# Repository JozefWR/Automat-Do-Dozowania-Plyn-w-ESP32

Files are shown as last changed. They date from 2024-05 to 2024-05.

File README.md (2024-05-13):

# Automat do Dozowania Płynów z Obsługą Zdalną (ESP32_BT)

## Opis projektu

Automat do dozowania płynów z możliwością obsługi zdalnej to zaawansowany projekt inżynierski, który łączy w sobie elektronikę i programowanie do stworzenia zintegrowanego systemu sterowania. Projekt został wykonany na Politechnice Koszalińskiej jako praca dyplomowa.

## Instalacja i konfiguracja

1. Sklonuj to repozytorium na swoje lokalne środowisko.
2. Zapoznaj się z dokumentacją techniczną zawartą w pliku `praca_inzynierska.pdf` dla szczegółów dotyczących budowy i działania urządzenia.
3. Zainstaluj wymagane oprogramowanie i biblioteki, jak opisano w dokumentacji.

## Schematy montażu i testowania

Nazwy elementów, moduły, zdjęcia i schematy montażu oraz testowania znajdują się w pliku `praca_inzynierska.pdf`. Wizualizacje te pomogą w zrozumieniu dokładnego procesu składania urządzenia i jego konfiguracji.

## Programowanie

Programowanie mikrokontrolera ESP32 odbywa się przez Arduino IDE. Kod źródłowy oraz szczegółowe instrukcje znajdują się w folderze i pliku `program_ESP32`.

## Zdjęcia i rysunki

- GotowyPrototyp - zdjęcie gotowego prototypu urządzenia.
- SchematKomunikacji - schemat komunikacji.
- SchematPłytkiPCB - schemat elektroniczny płytki PCB.
- PłytkaPCB
 - płytka PCB.
- SchematBlokowy - schemat blokowy działania automatu.
- Menu
  Tarowanie
  Nalewanie
- zrzuty ekranu z aplikacji mobilnej.

## Wykorzystane technologie

Projekt wykorzystuje następujące technologie:
- **Mikrokontroler ESP32**: Serce systemu, odpowiada za sterowanie działaniem urządzenia i komunikację zdalną.
- **Arduino IDE**: Środowisko programistyczne używane do pisania kodu dla mikrokontrolera.
- **Eagle CAD**: Oprogramowanie do projektowania płytek PCB, używane do tworzenia schematów elektronicznych i layoutów PCB.
- **Technologie mobilne**: Aplikacja mobilna umożliwia zdalne sterowanie urządzeniem i monitorowanie jego stanu.
- **Bluetooth**: Komunikacja bezprzewodowa między mikrokontrolerem a aplikacją mobilną.

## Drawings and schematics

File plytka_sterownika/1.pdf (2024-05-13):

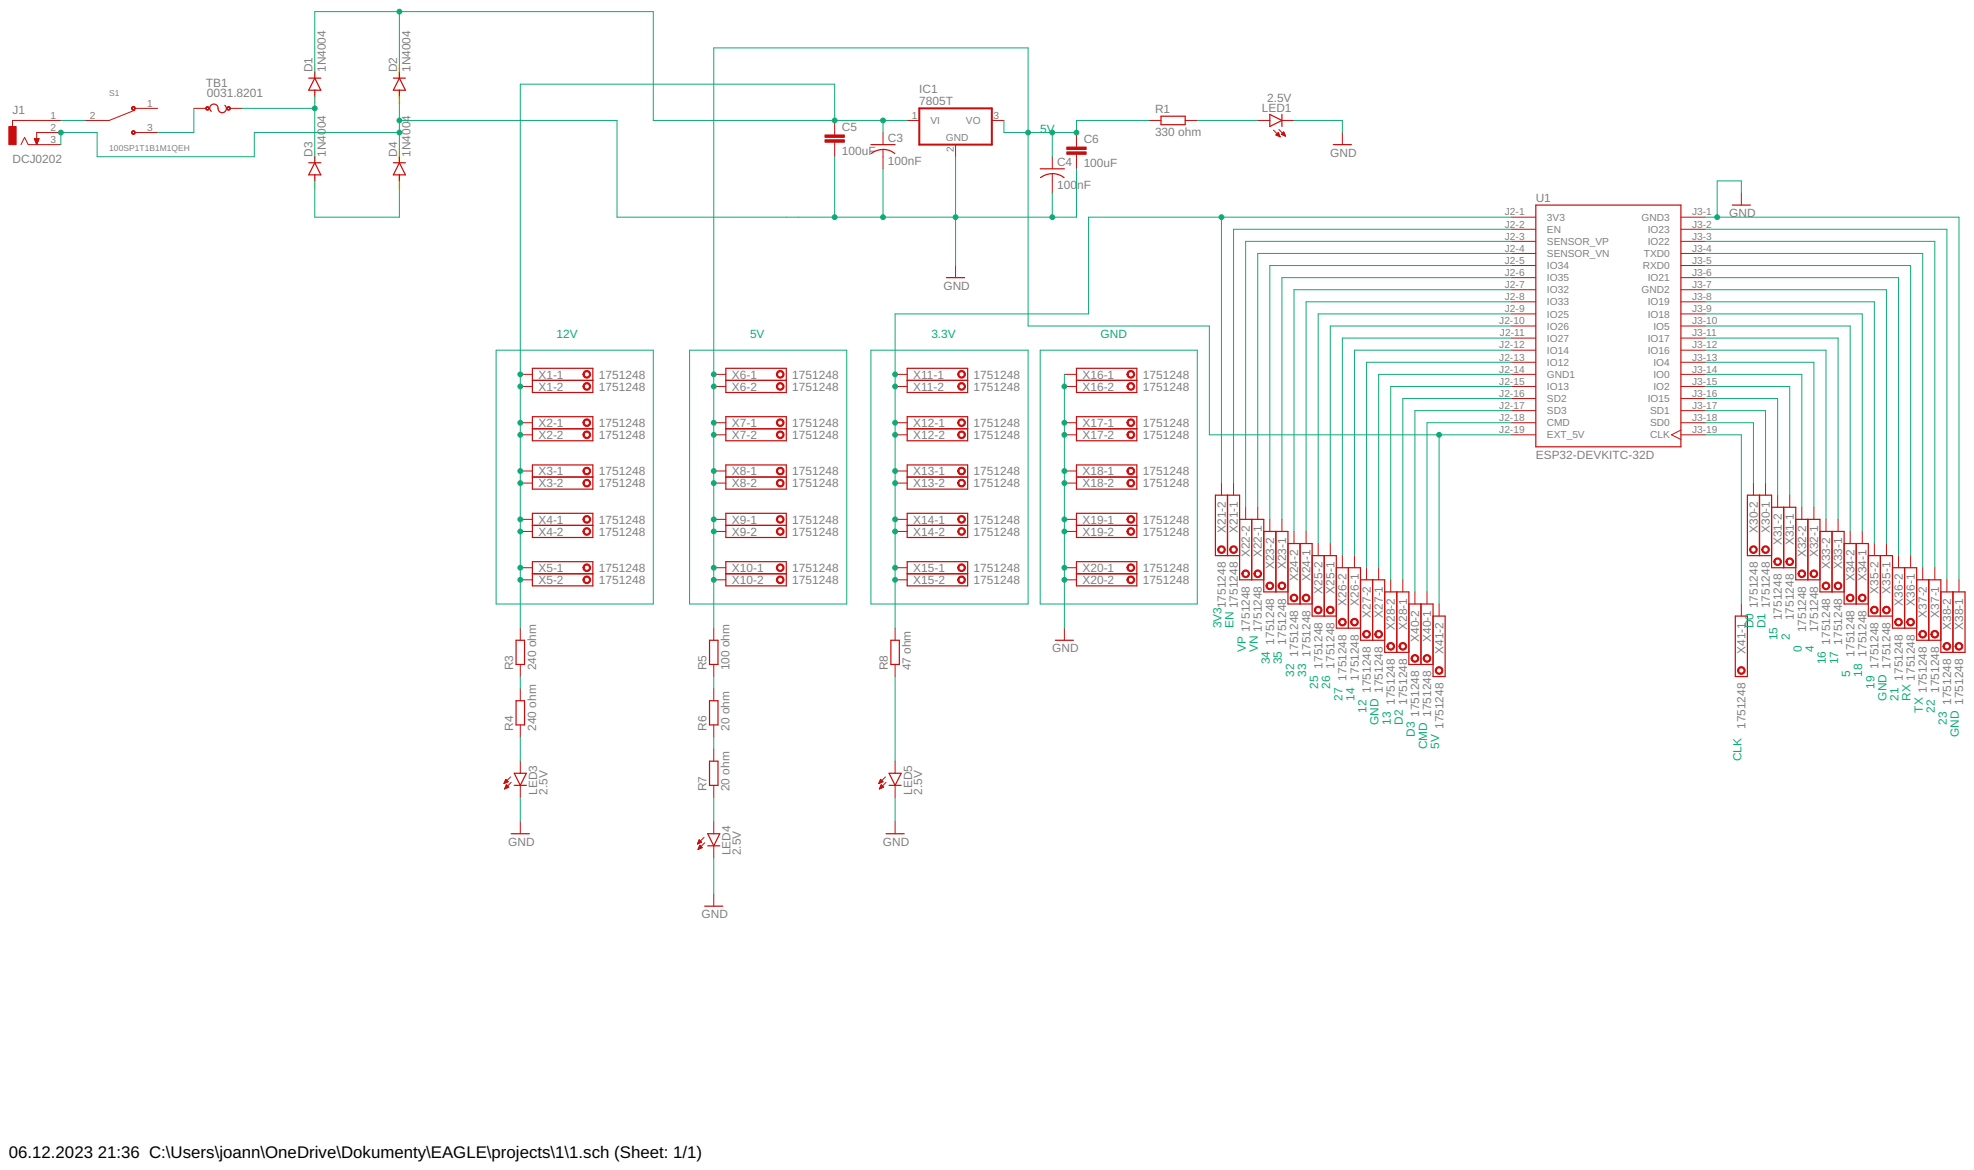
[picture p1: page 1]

J2-5 | J3-5 TXD0
J2-6 | J3-6 RXD0

J2-7 | J3-7
J2-8 | J3-8 GND2

J2-9 | J3-9
J2-10 | J3-10
J2-11 | J3-11
J2-12 | J3-12

06.12.2023 21:36 C:\Users\joann\OneDrive\Dokumenty\EAGLE\projects\1\1.sch (Sheet: 1/1)

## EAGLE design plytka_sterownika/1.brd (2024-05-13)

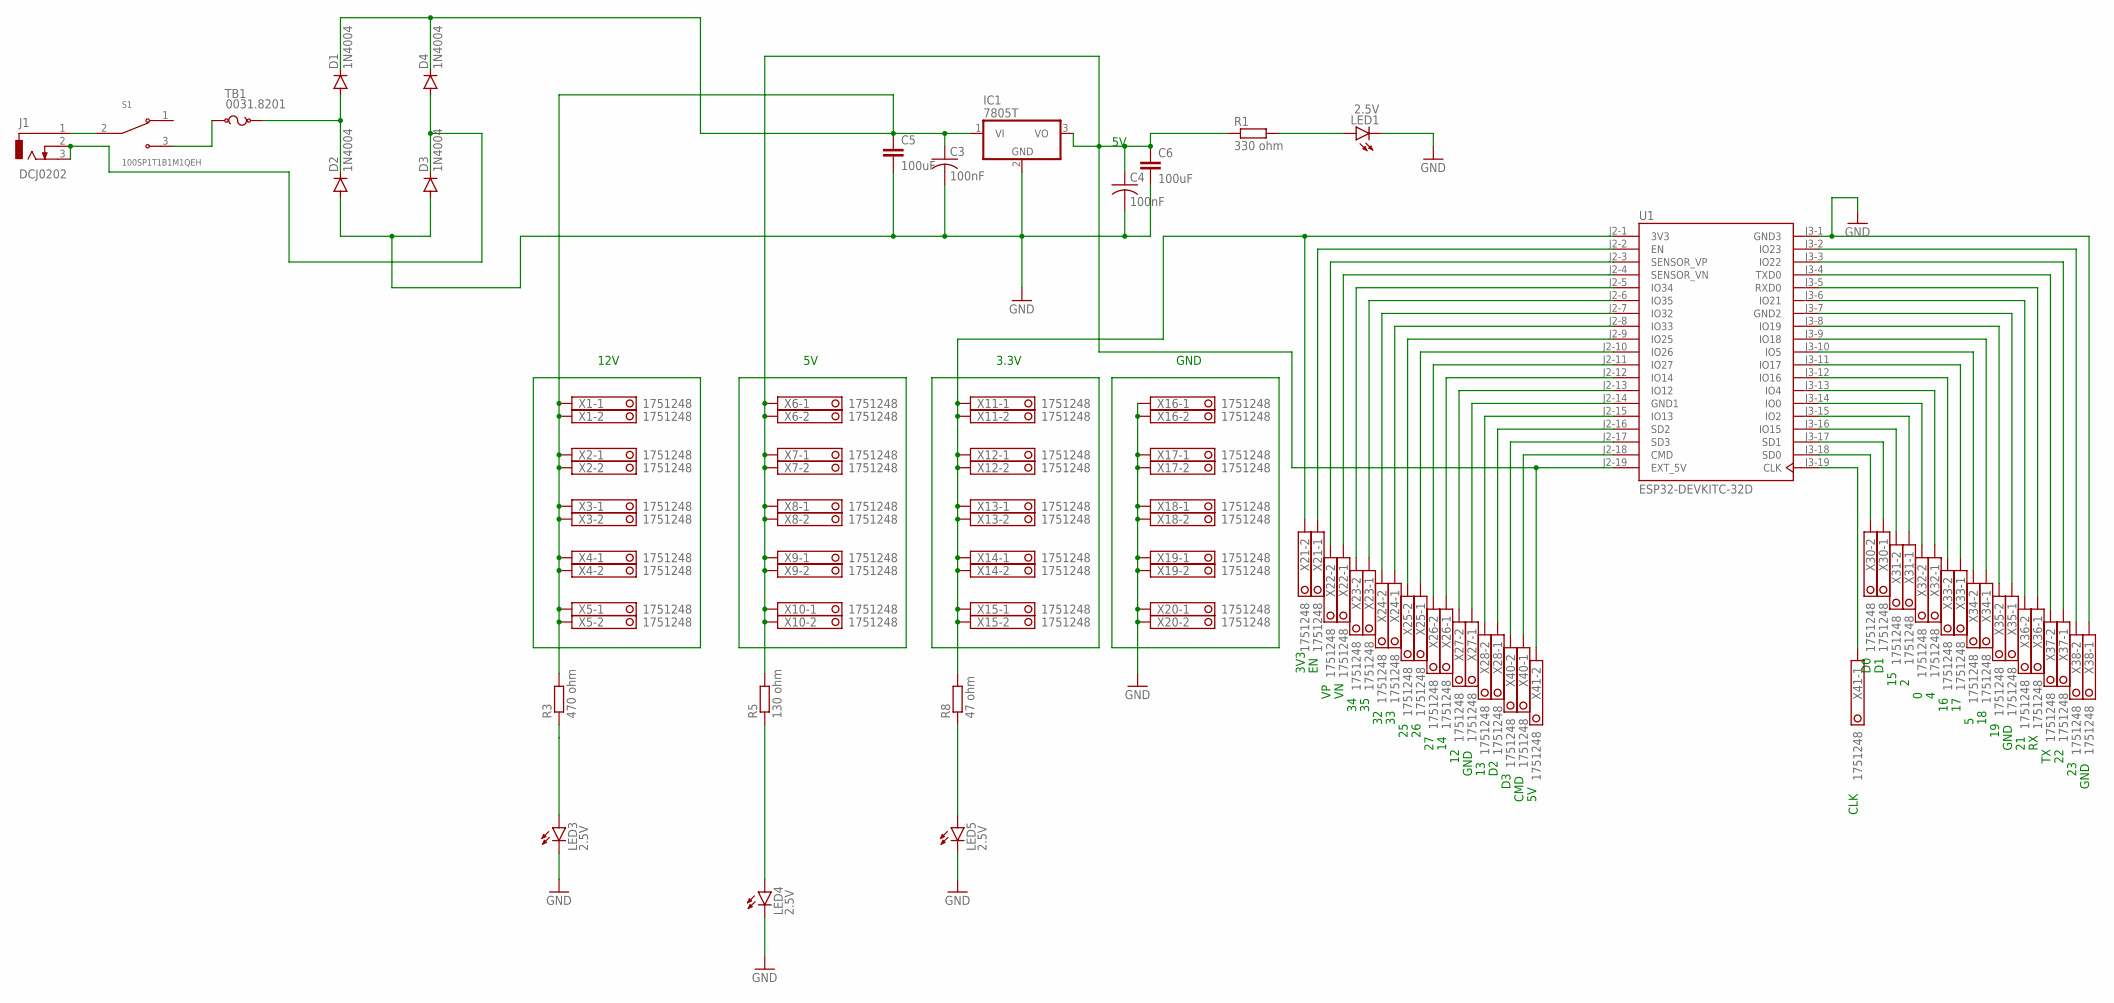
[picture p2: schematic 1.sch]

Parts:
C3, C4: 100nF; C025-024X044
C5, C6: 100uF; C025-050X050
D1, D2, D3, D4: 1N4004; DO41-10
IC1: 7805T; TO220H
J1: DCJ0202
LED1, LED3, LED4, LED5: 2.5V; LED3MM
R1: 330 ohm; 0207/10
R3: 470 ohm; 0207/10
R5: 130 ohm; 0207/10
R8: 47 ohm; 0207/10
S1: 100SP1T1B1M1QEH; SW_100SP1T1B1M1QEH
TB1: 0031.8201; SCHURTER_0031.8201
U1: ESP32-DEVKITC-32D; MODULE_ESP32-DEVKITC-32D
X1, X2, X3, X4, X5, X6, X7, X8, X9, X10, X11, X12, X13, X14, X15, X16, X17, X18, X19, X20, X21, X22, X23, X24, X25, X26, X27, X28, X30, X31, X32, X33, X34, X35, X36, X37, X38, X40, X41: 1751248

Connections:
GND: C3.2, C4.2, C5.2, C6.2, D2.A, D3.A, IC1.2 (GND), LED1.K (C), LED3.K (C), LED4.K (C), LED5.K (C), U1.J3-1 (GND3), X16.1, X16.2, X17.1, X17.2, X18.1, X18.2, X19.1, X19.2, X20.1, X20.2, X38.1
unnamed: D3.C, D4.A, J1.2, J1.3
unnamed: C4.1, C6.1, IC1.3 (VO), R1.1, R5.2, U1.J2-19 (EXT_5V), X6.1, X6.2, X7.1, X7.2, X8.1, X8.2, X9.1, X9.2, X10.1, X10.2, X41.2
unnamed: LED1.A, R1.2
unnamed: R8.2, U1.J2-1 (3V3), X11.1, X11.2, X12.1, X12.2, X13.1, X13.2, X14.1, X14.2, X15.1, X15.2, X21.2
unnamed: U1.J2-2 (EN), X21.1
unnamed: U1.J2-3 (SENSOR_VP), X22.2
unnamed: U1.J2-4 (SENSOR_VN), X22.1
unnamed: U1.J2-5 (IO34), X23.2
unnamed: U1.J2-6 (IO35), X23.1
unnamed: U1.J2-7 (IO32), X24.2
unnamed: U1.J2-8 (IO33), X24.1
unnamed: U1.J2-9 (IO25), X25.2
unnamed: U1.J2-10 (IO26), X25.1
unnamed: U1.J2-11 (IO27), X26.2
unnamed: U1.J2-12 (IO14), X26.1
unnamed: U1.J2-13 (IO12), X27.2
unnamed: U1.J2-14 (GND1), X27.1
unnamed: U1.J2-15 (IO13), X28.2
unnamed: U1.J2-16 (SD2), X28.1
unnamed: U1.J2-17 (SD3), X40.2
unnamed: U1.J2-18 (CMD), X40.1
unnamed: U1.J3-19 (CLK), X41.1
unnamed: U1.J3-18 (SD0), X30.2
unnamed: U1.J3-17 (SD1), X30.1
unnamed: U1.J3-16 (IO15), X31.2
unnamed: U1.J3-15 (IO2), X31.1
unnamed: U1.J3-14 (IO0), X32.2
unnamed: U1.J3-13 (IO4), X32.1
unnamed: U1.J3-12 (IO16), X33.2
unnamed: U1.J3-11 (IO17), X33.1
unnamed: U1.J3-10 (IO5), X34.2
unnamed: U1.J3-9 (IO18), X34.1
unnamed: U1.J3-8 (IO19), X35.2
unnamed: U1.J3-7 (GND2), X35.1
unnamed: U1.J3-6 (IO21), X36.2
unnamed: U1.J3-5 (RXD0), X36.1
unnamed: U1.J3-4 (TXD0), X37.2
unnamed: U1.J3-3 (IO22), X37.1
unnamed: U1.J3-2 (IO23), X38.2
unnamed: LED3.A, R3.1
unnamed: D1.A, D2.C, TB1.2
unnamed: S1.3, TB1.1
unnamed: C3.1, C5.1, D1.C, D4.C, IC1.1 (VI), R3.2, X1.1, X1.2, X2.1, X2.2, X3.1, X3.2, X4.1, X4.2, X5.1, X5.2
unnamed: J1.1, S1.2
unnamed: LED4.A, R5.1
unnamed: LED5.A, R8.1

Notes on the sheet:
12V
3.3V
GND
CMD
3V3
CLK

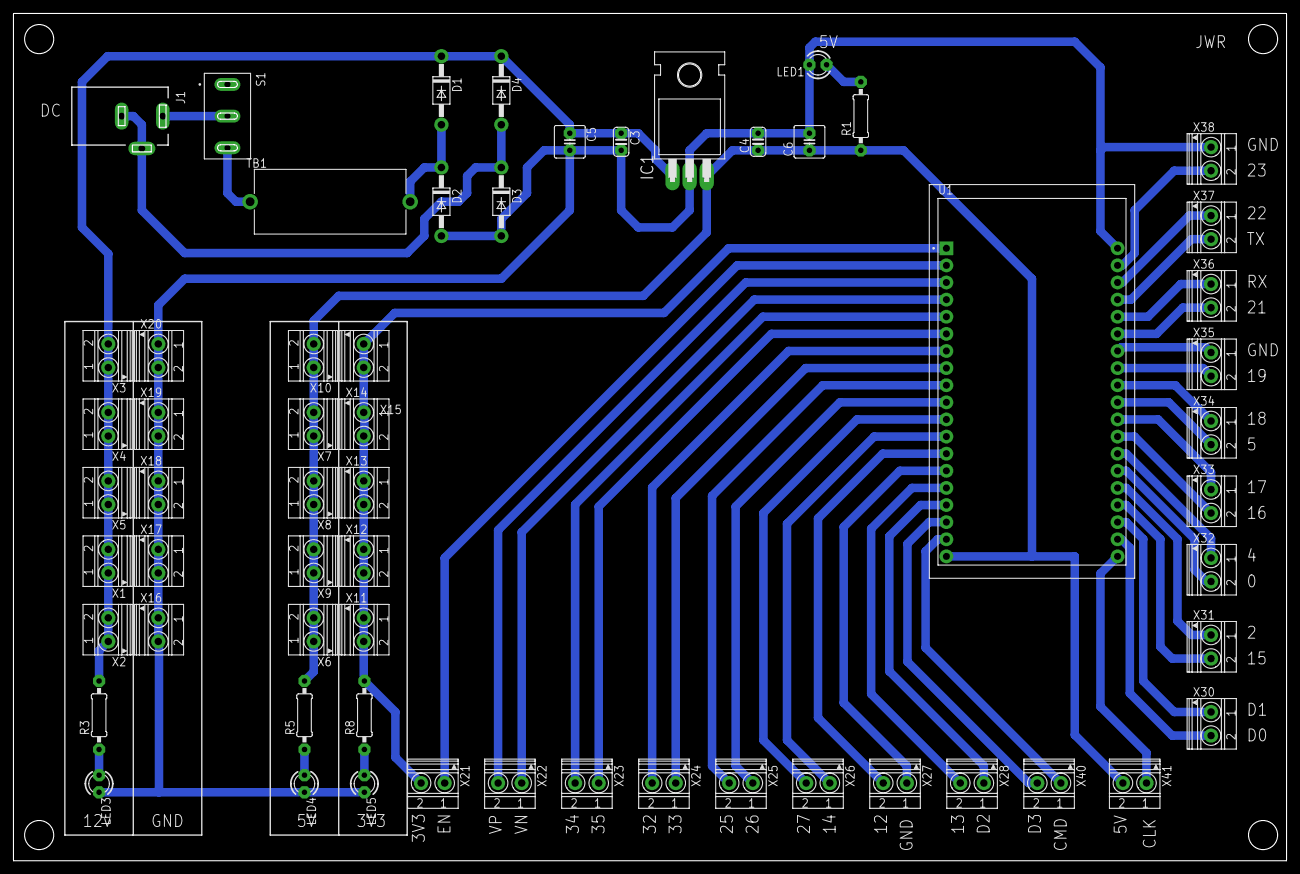
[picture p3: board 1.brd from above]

Board: 2 copper layers, 188.9 x 125.7 mm, 60 parts (0 on the bottom side), 47 nets.

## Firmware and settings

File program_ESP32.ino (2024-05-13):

#include <DFRobot_HX711_I2C.h>
#include <BluetoothSerial.h>
#include <Wire.h> 
#include <LiquidCrystal_I2C.h>

LiquidCrystal_I2C lcd(0x27, 16, 2);  // Adres I2C i rozmiar wyświetlacza
DFRobot_HX711_I2C MojaWaga;
BluetoothSerial SerialBT;

void setup() {
  Serial.begin(9600);
  SerialBT.begin("AutomatDoNapoji"); // Nazwa urządzenia Bluetooth
  lcd.init();                          // Inicjalizacja wyświetlacza
  lcd.backlight();                     // Włączenie podświetlenia
  delay(20000);
  inicjalizujAutomat();
}

void loop() {
  wyslijNaLCD("Wybierz napoj");
  wyslijNaLCD2("Z menu w apce!");
  wyslij("Wybierz napoj z menu:");
  bool restartLoop = false;

  wyswietlMenu();
  int wyborMenu = pobierzWyborMenu();
  if (wyborMenu > 0 && wyborMenu <= 20) {
    if (tarujWage()) {
      if (!przygotujNapojNaPodstawieWyboru(wyborMenu)) {
        restartLoop = true;
      }
    }
  } else {
    wyslij("Nieprawidlowy wybor");
  }

  if (restartLoop) {
    return;
  }

  wyczyscBuforySzeregowe();
}

void inicjalizujAutomat() {
  MojaWaga.begin();
  MojaWaga.setCalibration(2236.f);

  pinMode(15, OUTPUT); // Sok pomarańczowy
  digitalWrite(15, HIGH);
  pinMode(16, OUTPUT); // Sok jabłkowy
  digitalWrite(16, HIGH);
  pinMode(17, OUTPUT); // Sok ananasowy
  digitalWrite(17, HIGH);
  pinMode(18, OUTPUT); // Woda gazowana
  digitalWrite(18, HIGH);
  pinMode(19, OUTPUT); // Mleko
  digitalWrite(19, HIGH);

  pinMode(32, OUTPUT); // Syrop malinowy
  digitalWrite(32, HIGH);
  pinMode(33, OUTPUT); // Cytryna wyciskana
  digitalWrite(33, HIGH);
  pinMode(25, OUTPUT); // Tonik
  digitalWrite(25, HIGH);
  pinMode(26, OUTPUT); // Cola
  digitalWrite(26, HIGH);
  pinMode(27, OUTPUT); // Lemoniada gazowana
  digitalWrite(27, HIGH);
}

void wyslij(String wiadomosc) {
  Serial.println(wiadomosc);
  SerialBT.println(wiadomosc);
}

void wyslijNaLCD(String wiadomosc) {
  lcd.clear();
  lcd.setCursor(0, 0);
  lcd.print(wiadomosc);
}

void wyslijNaLCD2(String wiadomosc) {
  lcd.setCursor(0, 1);
  lcd.print("                "); // Czyszczenie drugiej linii
  lcd.setCursor(0, 1);
  lcd.print(wiadomosc);
}

void wyswietlMenu() {
  wyslij("1. Orzeźwiający Mix");
  wyslij("2. Jesienna Harmonia");
  wyslij("3. Tropikalna Bryza");
  wyslij("4. Malinowa Rozkosz");
  wyslij("5. Cytrusowy Zing");
  wyslij("6. Klasyczna Cola Mix");
  wyslij("7. Lemoniadowe Orzeźwienie");
  wyslij("8. Klasyczna Cola Mix");
  wyslij("9. Pomarańczowa Fantazja");
  wyslij("10. Ananasowa Fuzja");
  wyslij("11. Lemon & Cola");
  wyslij("12. Słoneczny Koktajl");
  wyslij("12. Mleczny Twist");
  wyslij("13. Lekka Cola");
  wyslij("14. Cytrynowy Chłód");
  wyslij("15. Malinowy Dream");
  wyslij("16. Egzotyczny Mix");
  wyslij("17. Orzeźwiający Cytrus");
  wyslij("18. Lemoniada Plus");
  wyslij("19. Tropikalna Cola");
  wyslij("20. Malinowa Cola");
}

int pobierzWyborMenu() {
  while (!(SerialBT.available() || Serial.available())) {
    delay(10);
  }
  
  if (SerialBT.available()) {
    return SerialBT.parseInt();
  } else if (Serial.available()) {
    return Serial.parseInt();
  }
  
  return -1;
}

bool tarujWage() {
  wyslijNaLCD("Tarowanie...");
  wyslijNaLCD2("Ostroznie!");
  wyslij("Umieść szklankę na wadze i naciśnij 't', aby wytarować...");
  wyslij("Naciśnij 'm', aby anulować i wrócić do menu.");
  char result = czekajNaDaneZTimeoutem(15000, 't', 'm');
  if (result == 't') {
    MojaWaga.peel();
    wyslij("Waga wytarowana.");
    return true;
  } else if (result == 'm') {
    wyslij("Wybór anulowany, powrót do menu.");
    return false;
  } else {
    wyslij("Czas na tarowanie upłynął, powrót do menu.");
    return false;
  }
}

char czekajNaDaneZTimeoutem(unsigned long czasTimeoutu, char oczekiwanyZnak, char znakAnulujacy) {
  unsigned long czasStartu = millis();
  while (millis() - czasStartu < czasTimeoutu) {
    if (Serial.available() || SerialBT.available()) {
      char znak = Serial.available() ? Serial.read() : SerialBT.read();
      if (znak == oczekiwanyZnak || znak == znakAnulujacy) {
        wyczyscBuforySzeregowe();
        return znak;
      }
    }
    delay(10);
  }
  return 'x'; // Gdy czas się skończy, zwracamy 'x' jako sygnał upływu czasu
}

bool przygotujNapojNaPodstawieWyboru(int wybor) {
  switch (wybor) {
    case 1: // Orzeźwiający Mix
      if (!nalejSkladnik("Sok pomaranczowy", 30, 15) || !nalejSkladnik("Woda gazowana", 20, 18) || !nalejSkladnik("Lemoniada gazowana", 10, 27) || !nalejSkladnik("Sok jablkowy", 40, 16)) {
        return false;
      }
      break;
    case 2: // Jesienna Harmonia
      if (!nalejSkladnik("Sok jablkowy", 40, 16) || !nalejSkladnik("Lemoniada gazowana", 30, 27) || !nalejSkladnik("Woda gazowana", 30, 18)) {
        return false;
      }
      break;
    case 3: // Tropikalna Bryza
      if (!nalejSkladnik("Sok ananasowy", 25, 17) || !nalejSkladnik("Sok pomaranczowy", 25, 15) || !nalejSkladnik("Tonik", 50, 25)) {
        return false;
      }
      break;
    case 4: // Malinowa Rozkosz
      if (!nalejSkladnik("Mleko", 50, 19) || !nalejSkladnik("Syrop malinowy", 20, 32) || !nalejSkladnik("Woda gazowana", 30, 18)) {
        return false;
      }
      break;
    case 5: // Cytrusowy Zing
      if (!nalejSkladnik("Sok pomaranczowy", 30, 15) || !nalejSkladnik("Sok cytrynowy", 20, 33) || !nalejSkladnik("Cola", 50, 26)) {
        return false;
      }
      break;
    case 6: // Klasyczna Cola Mix
      if (!nalejSkladnik("Cola", 60, 26) || !nalejSkladnik("Woda gazowana", 40, 18)) {
        return false;
      }
      break;
    case 7: // Lemoniadowe Orzeźwienie
      if (!nalejSkladnik("Lemoniada gazowana", 70, 27) || !nalejSkladnik("Sok jablkowy", 30, 16)) {
        return false;
      }
      break;
    case 8: // Pomarańczowa Fantazja
      if (!nalejSkladnik("Sok pomaranczowy", 50, 15) || !nalejSkladnik("Mleko", 25, 19) || !nalejSkladnik("Lemoniada gazowana", 25, 27)) {
        return false;
      }
      break;
    case 9: // Ananasowa Fuzja
      if (!nalejSkladnik("Sok ananasowy", 30, 17) || !nalejSkladnik("Tonik", 40, 25) || !nalejSkladnik("Lemoniada gazowana", 30, 27)) {
        return false;
      }
      break;
    case 10: // Lemon & Cola
      if (!nalejSkladnik("Cola", 50, 26) || !nalejSkladnik("Sok cytrynowy", 50, 33)) {
        return false;
      }
      break;
    case 11: // Słoneczny Koktajl
      if (!nalejSkladnik("Sok pomaranczowy", 50, 15) || !nalejSkladnik("Sok jablkowy", 25, 16) || !nalejSkladnik("Lemoniada gazowana", 25, 27)) {
        return false;
      }
      break;
    case 12: // Mleczny Twist
      if (!nalejSkladnik("Mleko", 70, 19) || !nalejSkladnik("Cola", 30, 26)) {
        return false;
      }
      break;
    case 13: // Lekka Cola
      if (!nalejSkladnik("Cola", 50, 26) || !nalejSkladnik("Woda gazowana", 50, 18)) {
        return false;
      }
      break;
    case 14: // Cytrynowy Chłód
      if (!nalejSkladnik("Tonik", 50, 25) || !nalejSkladnik("Sok cytrynowy", 25, 33) || !nalejSkladnik("Cola", 25, 26)) {
        return false;
      }
      break;
    case 15: // Malinowy Dream
      if (!nalejSkladnik("Syrop malinowy", 50, 32) || !nalejSkladnik("Mleko", 50, 19)) {
        return false;
      }
      break;
    case 16: // Egzotyczny Mix
      if (!nalejSkladnik("Sok ananasowy", 40, 17) || !nalejSkladnik("Sok pomaranczowy", 30, 15) || !nalejSkladnik("Lemoniada gazowana", 30, 27)) {
        return false;
      }
      break;
    case 17: // Orzeźwiający Cytrus
      if (!nalejSkladnik("Sok pomaranczowy", 40, 15) || !nalejSkladnik("Sok cytrynowy", 30, 33) || !nalejSkladnik("Cola", 30, 26)) {
        return false;
      }
      break;
    case 18: // Lemoniada Plus
      if (!nalejSkladnik("Lemoniada gazowana", 70, 27) || !nalejSkladnik("Sok jablkowy", 30, 16)) {
        return false;
      }
      break;
    case 19: // Tropikalna Cola
      if (!nalejSkladnik("Sok ananasowy", 35, 17) || !nalejSkladnik("Cola", 35, 26) || !nalejSkladnik("Tonik", 30, 25)) {
        return false;
      }
      break;
    case 20: // Malinowa Cola
      if (!nalejSkladnik("Syrop malinowy", 40, 32) || !nalejSkladnik("Cola", 60, 26)) {
        return false;
      }
      break;
    default:
      wyslij("Nieprawidłowy wybór. Spróbuj ponownie.");
      return false;
  }
  wyslij("Twój napój jest gotowy! Odbierz go!");
  wyslijNaLCD("Napoj gotowy!");
  wyslijNaLCD2("Odbierz go!");
  return true;
}

bool nalejSkladnik(String skladnik, int waga, int pin) {
  int startowaWaga = MojaWaga.readWeight();
  int aktualnaWaga;
  digitalWrite(pin, LOW); // Rozpoczęcie nalewania

  wyslijNaLCD(skladnik);
  delay(1000); // Czekaj sekundę, aby wyświetlić nazwę składnika

  do {
    aktualnaWaga = MojaWaga.readWeight();
    if (aktualnaWaga - startowaWaga >= waga) {
      break;
    }

    String komunikatLCD = String(aktualnaWaga - startowaWaga) + " g";
    String komunikatSerial = "Nalano " + skladnik + ": " + komunikatLCD;
    wyslij(komunikatSerial);
    wyslijNaLCD2("Nalano: "+komunikatLCD);

    if (Serial.available() || SerialBT.available()) {
      char znak = Serial.available() ? Serial.read() : SerialBT.read();
      if (znak == 'm') {
        digitalWrite(pin, HIGH); // Zakończenie nalewania
        wyslij("Przerwano, powrót do menu.");
        return false;
      }
    }
    delay(500);
  } while (true);

  digitalWrite(pin, HIGH); // Zakończenie nalewania
  return true;
}

void wyczyscBuforySzeregowe() {
  while (Serial.available() > 0) {
    Serial.read();
  }
  while (SerialBT.available() > 0) {
    SerialBT.read();
  }
}
